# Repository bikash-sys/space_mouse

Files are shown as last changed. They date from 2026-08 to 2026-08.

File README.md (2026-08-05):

# 3D Space Mouse

A USB HID 6‑DoF "space mouse" implementation for Raspberry Pi Pico using three MLX90393 magnetometers. The Pico exposes a generic gamepad HID (X, Y, Z, Rx, Ry, Rz) over USB and sends machine-readable sensor/debug output to the serial port for integration.

## Features
- HID Gamepad device (6 axes + buttons) via TinyUSB
- Sensor fusion from three MLX90393 magnetometers
- Serial debug output:
  - Raw sensor lines per sensor
  - Fused axis lines (Tx, Ty, Tz, Rx, Ry, Rz)
  - Machine-parsable CSV line starting with `AX,` for external consumers
- PlatformIO project for Raspberry Pi Pico (Arduino framework)

## Hardware
Required components:
- Raspberry Pi Pico (or compatible RP2040 board)
- 3 × MLX90393 magnetometer breakout boards (I2C)
- Wires / connectors, 3.3V power, ground

Sensor addresses in the code:
- ADDR_MAG1 = 0x0C (bottom)
- ADDR_MAG2 = 0x0D (top-left)
- ADDR_MAG3 = 0x0E (top-right)

Note: The address selection depends on your MLX90393 breakout solder jumpers or wiring. Ensure each sensor has a unique I2C address matching the defines above, or change the defines in code.

Typical wiring (per MLX90393 breakout):
- VCC -> 3.3V
- GND -> GND
- SDA -> Pico SDA (I2C0/1 depending on your wiring)
- SCL -> Pico SCL
- Ensure I2C pull-ups are present if your breakout doesn't include them.

Physical placement: sensors should be arranged around the knob (unit circle, ~120° apart):
- mag1: bottom
- mag2: top-left
- mag3: top-right

## Wiring
<Screenshot 2026-08-05 at 11 19 41 PM

{im really sorry for such wiring but I had no option I cant find the exact magnetometer any where hope u get it }

## Software dependencies
- PlatformIO
- Platform: maxgerhardt/platform-raspberrypi (as referenced in platformio.ini)
- Board: pico
- Framework: Arduino (earlephilhower core)
- Libraries (PlatformIO `lib_deps`):
  - adafruit/Adafruit MLX90393
  - adafruit/Adafruit BusIO

## BOM
| S.No. | Component | Qty | Unit Price | Total | Purchase |
|---:|---|---:|---:|---:|---|
| 1 | Raspberry Pi Pico | 1 | $4.10 | **$4.10** | [Robu.in – Raspberry Pi Pico](https://robu.in/product/raspberry-pi-pico/) |
| 2 | SmartElex MLX90393 Triple-Axis Magnetometer | 3 | $3.00 | **$9.00** | [Robocraze – MLX90393](https://robocraze.com/products/smartelex-mlx90393-triple-axis-magnetometer-high-precision-magnetic-field-sensor) |
| 3 | 10 × 10 × 10 mm Neodymium Block Magnet | 3 | - | **$1.40** | [ElectroPi – Neodymium Magnet](https://www.electropi.in/10mm-x-10mm-x-10mm-10x10x10-mm-neodymium-block-magnet) |
| 4 | 3D Printed Base | 1 | — | — | Self printed |
| 5 | 3D Printed Knob | 1 | — | — | Self printed |

## Build & Flash (PlatformIO)
From the repository root:
- Build: pio run -e pico
- Upload: pio run -e pico -t upload
- Monitor serial: pio device monitor -e pico -b 115200

If using VSCode + PlatformIO, open the project, choose the `pico` environment and Build / Upload from the UI.

## Serial output format
The firmware prints several formats for debugging and external consumers:

1) Sensor raw format (human friendly):
   [0x0c] x=  12.3 y=  -4.1 z=  88.0   [0x0d] x=...  [0x0e] x=...

2) Fused axes (human friendly):
   Tx=  0.12 Ty= -0.03 Tz=  0.00 Rx=  0.00 Ry=  0.00 Rz=  0.01

3) Machine readable CSV (one line per cycle):
   AX,Tx,Ty,Tz,Rx,Ry,Rz,btn1,btn2
   Example:
   AX,0.0123,-0.0034,0.0000,0.0000,0.0000,0.0001,0,0

The HID report contains 6 int8 axes mapped to X,Y,Z,Rx,Ry,Rz and a buttons bitmask. Buttons are currently not wired in the code (TODO).

## Calibration & Tuning
- The firmware performs a quick calibration on boot: keep the knob still during boot (~200 ms) so offsets are captured.
- Key tuning constants are in the source (main.cpp):
  - GAIN_T / GAIN_R — per-axis gains for translation/rotation
  - DEAD_T / DEAD_R — deadzone thresholds
  - SMOOTH_TAU_S — smoothing time constant
  - OUTPUT_SCALE — scales normalized axis to int8 HID range
  - SIGN_AXIS — per-axis sign flips
- Adjust these constants if you see poor sensitivity, clipping, or excessive noise.

## Troubleshooting
- "One or more sensors failed to init" printed on serial:
  - Check wiring and power (3.3V vs 5V)
  - Verify each sensor's I2C address / solder jumpers
  - Confirm SDA/SCL connections and I2C pins on the Pico
  - Use an I2C scanner to confirm addresses on the bus
- USB/HID not recognized:
  - Ensure the Pico is in normal USB device mode and your USB cable supports data (not charge-only)
- No serial output:
  - Check Baud (115200) and correct serial port
  - Ensure the board is running and not stuck (use LED/debug prints)

## CAD Models




## Assembly
The top part with magnetic housing goes into the base plate then connect the magnetometers and fix them in the gaps add magnets in housing and then just download the code folder open with vscode+platform io and just choose env pico and upload

## Build


## Contributing
- Bug reports, PRs and improvements are welcome.
- Please describe hardware used and any wiring changes when submitting sensor-related fixes.

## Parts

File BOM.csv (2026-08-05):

S.No. | Component | Quantity | Unit Price (USD) | Total Price (USD) | Purchase Link
1 | Raspberry Pi Pico | 1 | 4.10 | 4.10 | https://robu.in/product/raspberry-pi-pico/
2 | SmartElex MLX90393 Triple-Axis Magnetometer | 3 | 3.00 | 9.00 | https://robocraze.com/products/smartelex-mlx90393-triple-axis-magnetometer
3 | 10x10x10 mm Neodymium Block Magnet | 3 |  | 1.40 | https://www.electropi.in/10mm-x-10mm-x-10x10x10-mm-neodymium-block-magnet
4 | 3D Printed Base | 1 |  |  | Self printed
5 | 3D Printed Knob | 1 |  |  | Self printed

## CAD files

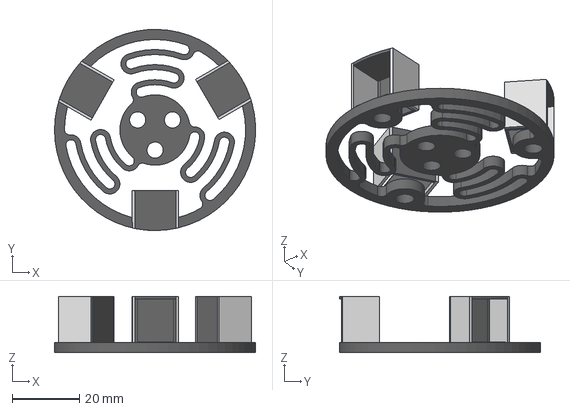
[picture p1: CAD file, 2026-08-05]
CAD/top_magnet holder.step
60.0 x 60.0 x 16.8 mm

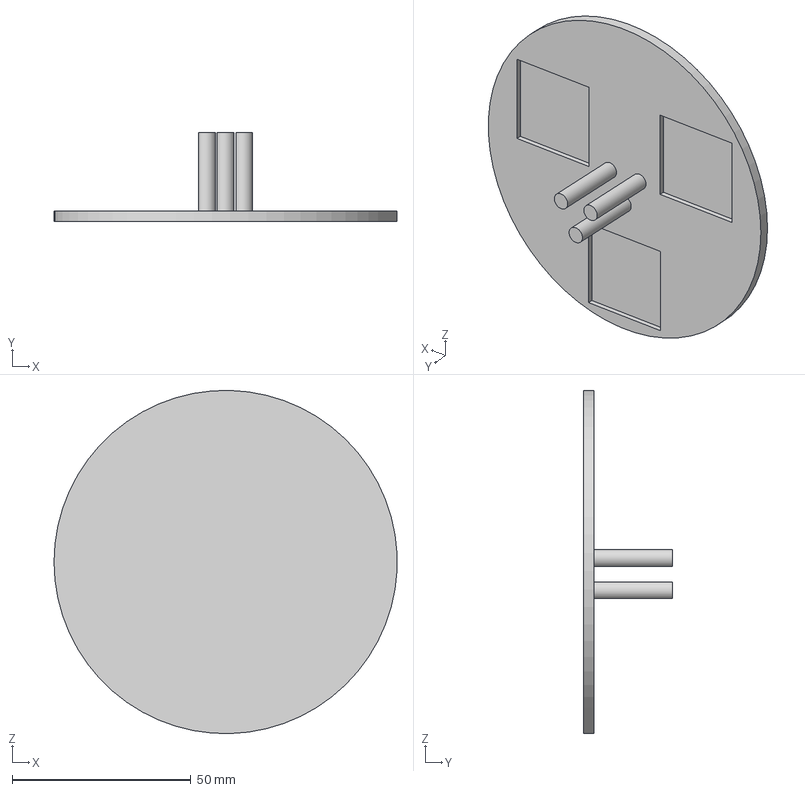
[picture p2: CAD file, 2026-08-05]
CAD/base.step
95.9 x 25.0 x 96.0 mm

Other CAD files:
CAD/base.f3d
CAD/top_magnet holder.f3d

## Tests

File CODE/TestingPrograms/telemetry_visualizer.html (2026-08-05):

Space Mouse

# 6DOF Telemetry

no device detected

TRANSLATION

Tx

0.00

Ty

0.00

Tz

0.00

ROTATION

Rx

0.00

Ry

0.00

Rz

0.00

BUTTONS

1

2

RAW GAMEPAD.AXES[]

waiting for device...

Move/tilt the knob to wake the browser's Gamepad API.
If rotation looks mapped to the wrong axis, the raw values
above show the true index order your browser reports.

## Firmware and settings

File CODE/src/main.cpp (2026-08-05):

#include <Arduino.h>
#include <Adafruit_TinyUSB.h>
#include <Adafruit_MLX90393.h>
#include <math.h>


uint8_t const desc_hid_report[] = {
  TUD_HID_REPORT_DESC_GAMEPAD()
};

Adafruit_USBD_HID usb_hid;

#define ADDR_MAG1 0x0C  // bottom
#define ADDR_MAG2 0x0D  // top left
#define ADDR_MAG3 0x0E  // top right

Adafruit_MLX90393 mag1 = Adafruit_MLX90393();
Adafruit_MLX90393 mag2 = Adafruit_MLX90393();
Adafruit_MLX90393 mag3 = Adafruit_MLX90393();

float off1x, off1y, off1z;
float off2x, off2y, off2z;
float off3x, off3y, off3z;


const float GAIN_T[3]   = {28.0, 28.0, 24.0};   // Tx, Ty, Tz
const float GAIN_R[3]   = {18.0, 18.0, 20.0};   // Rx, Ry, Rz
const int   SIGN_AXIS[6] = {-1, 1, -1, 1, 1, 1};
const float DEAD_T = 16.0;
const float DEAD_R = 20.0;
const float SMOOTH_TAU_S = 0.08;

const float OUTPUT_SCALE = 25.0;

const float POS[3][2] = {
  {0.0f, -1.0f},                          // mag1 - bottom
  {-0.8660254f, 0.5f},                    // mag2 - top left
  {0.8660254f, 0.5f},                     // mag3 - top right
};

float smoothed[6] = {0, 0, 0, 0, 0, 0};
unsigned long last_t = 0;

float dead_zone(float value, float threshold) {
  if (fabs(value) < threshold) return 0.0f;
  return value > 0 ? value - threshold : value + threshold;
}

int8_t clamp_to_int8(float v) {
  if (v > 127) v = 127;
  if (v < -127) v = -127;
  return (int8_t)v;
}

void printRawSensors(float x1, float y1, float z1,
                      float x2, float y2, float z2,
                      float x3, float y3, float z3) {
  Serial.print("[0x"); Serial.print(ADDR_MAG1, HEX); Serial.print("] x=");
  Serial.print(x1, 1); Serial.print(" y="); Serial.print(y1, 1);
  Serial.print(" z="); Serial.print(z1, 1); Serial.print("   ");

  Serial.print("[0x"); Serial.print(ADDR_MAG2, HEX); Serial.print("] x=");
  Serial.print(x2, 1); Serial.print(" y="); Serial.print(y2, 1);
  Serial.print(" z="); Serial.print(z2, 1); Serial.print("   ");

  Serial.print("[0x"); Serial.print(ADDR_MAG3, HEX); Serial.print("] x=");
  Serial.print(x3, 1); Serial.print(" y="); Serial.print(y3, 1);
  Serial.print(" z="); Serial.println(z3, 1);
}

void printFusedAxes(float Tx, float Ty, float Tz, float Rx, float Ry, float Rz) {
  Serial.print("  Tx="); Serial.print(Tx, 2);
  Serial.print(" Ty=");  Serial.print(Ty, 2);
  Serial.print(" Tz=");  Serial.print(Tz, 2);
  Serial.print(" Rx=");  Serial.print(Rx, 2);
  Serial.print(" Ry=");  Serial.print(Ry, 2);
  Serial.print(" Rz=");  Serial.println(Rz, 2);
}

void printMachineAxes(float Tx, float Ty, float Tz, float Rx, float Ry, float Rz,
                       bool btn1, bool btn2) {
  Serial.print("AX,");
  Serial.print(Tx, 4); Serial.print(",");
  Serial.print(Ty, 4); Serial.print(",");
  Serial.print(Tz, 4); Serial.print(",");
  Serial.print(Rx, 4); Serial.print(",");
  Serial.print(Ry, 4); Serial.print(",");
  Serial.print(Rz, 4); Serial.print(",");
  Serial.print(btn1 ? 1 : 0); Serial.print(",");
  Serial.println(btn2 ? 1 : 0);
}

bool initSensor(Adafruit_MLX90393 &s, uint8_t addr) {
  if (!s.begin_I2C(addr, &Wire)) return false;
  s.setGain(MLX90393_GAIN_1X);
  s.setResolution(MLX90393_X, MLX90393_RES_16);
  s.setResolution(MLX90393_Y, MLX90393_RES_16);
  s.setResolution(MLX90393_Z, MLX90393_RES_16);
  s.setOversampling(MLX90393_OSR_3);
  s.setFilter(MLX90393_FILTER_5);
  return true;
}

void setup() {
  Serial.begin(115200);

  usb_hid.setPollInterval(2);
  usb_hid.setReportDescriptor(desc_hid_report, sizeof(desc_hid_report));
  usb_hid.begin();

  Wire.begin();

  bool ok1 = initSensor(mag1, ADDR_MAG1);
  bool ok2 = initSensor(mag2, ADDR_MAG2);
  bool ok3 = initSensor(mag3, ADDR_MAG3);

  if (!ok1 || !ok2 || !ok3) {
    Serial.println("One or more sensors failed to init - check wiring/addresses.");
  }

  delay(200);
  mag1.readData(&off1x, &off1y, &off1z);
  mag2.readData(&off2x, &off2y, &off2z);
  mag3.readData(&off3x, &off3y, &off3z);

  last_t = millis();
}

void loop() {
  float x1, y1, z1, x2, y2, z2, x3, y3, z3;
  mag1.readData(&x1, &y1, &z1);
  mag2.readData(&x2, &y2, &z2);
  mag3.readData(&x3, &y3, &z3);

  float m1x = x1 - off1x, m1y = y1 - off1y, m1z = z1 - off1z;
  float m2x = x2 - off2x, m2y = y2 - off2y, m2z = z2 - off2z;
  float m3x = x3 - off3x, m3y = y3 - off3y, m3z = z3 - off3z;

  float Tx = (m1x + m2x + m3x) / 3.0f;
  float Ty = (m1y + m2y + m3y) / 3.0f;
  float Tz = (m1z + m2z + m3z) / 3.0f;

  float Rx = sqrtf(3.0f) * (m2z + m3z - 2 * m1z) / 3.0f;
  float Ry = m3z - m2z;

  float Rz = 0.0f;
  Rz += POS[0][0] * m1y - POS[0][1] * m1x;
  Rz += POS[1][0] * m2y - POS[1][1] * m2x;
  Rz += POS[2][0] * m3y - POS[2][1] * m3x;

  float axes[6]  = {Tx, Ty, Tz, Rx, Ry, Rz};
  float dead[6]  = {DEAD_T, DEAD_T, DEAD_T, DEAD_R, DEAD_R, DEAD_R};
  float gain[6]  = {GAIN_T[0], GAIN_T[1], GAIN_T[2], GAIN_R[0], GAIN_R[1], GAIN_R[2]};

  unsigned long now = millis();
  float dt = (now - last_t) / 1000.0f;
  last_t = now;
  float alpha = dt / (SMOOTH_TAU_S + dt);

  for (int i = 0; i < 6; i++) {
    float v = dead_zone(axes[i], dead[i]);
    v = v / gain[i] * SIGN_AXIS[i];
    smoothed[i] += alpha * (v - smoothed[i]);
  }

  hid_gamepad_report_t report;
  report.x  = clamp_to_int8(smoothed[0] * OUTPUT_SCALE);
  report.y  = clamp_to_int8(smoothed[1] * OUTPUT_SCALE);
  report.z  = clamp_to_int8(smoothed[2] * OUTPUT_SCALE);
  report.rx = clamp_to_int8(smoothed[3] * OUTPUT_SCALE);
  report.ry = clamp_to_int8(smoothed[4] * OUTPUT_SCALE);
  report.rz = clamp_to_int8(smoothed[5] * OUTPUT_SCALE);
  report.hat = 0;
  report.buttons = 0;

  if (usb_hid.ready()) {
    usb_hid.sendReport(0, &report, sizeof(report));
  }

  printRawSensors(x1, y1, z1, x2, y2, z2, x3, y3, z3);
  printFusedAxes(Tx, Ty, Tz, Rx, Ry, Rz);
  printMachineAxes(smoothed[0], smoothed[1], smoothed[2],
                    smoothed[3], smoothed[4], smoothed[5],
                    false, false);

  delay(20);
}
